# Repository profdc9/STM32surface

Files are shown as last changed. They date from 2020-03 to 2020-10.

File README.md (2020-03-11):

# STM32surface
This is a Bluepill-compatible devboard for the STM32F103C8T6 microcontroller.
It uses 0805 surface mount parts and a few through hole parts that can be easily obtained as
generic components.  It is intended to be an alternative should the 
should the Bluepill not be available, especially given the number of fake parts that have appeared lately.
The layout is somewhat optimized to be RFI resistant given it is a two-layer board
This material is copyrighted by Daniel Marks (KW4TI) and licensed under
the Creative Commons License CC-BY-SA 4.0.  Software is copyrighted using the zlib
open-source license.

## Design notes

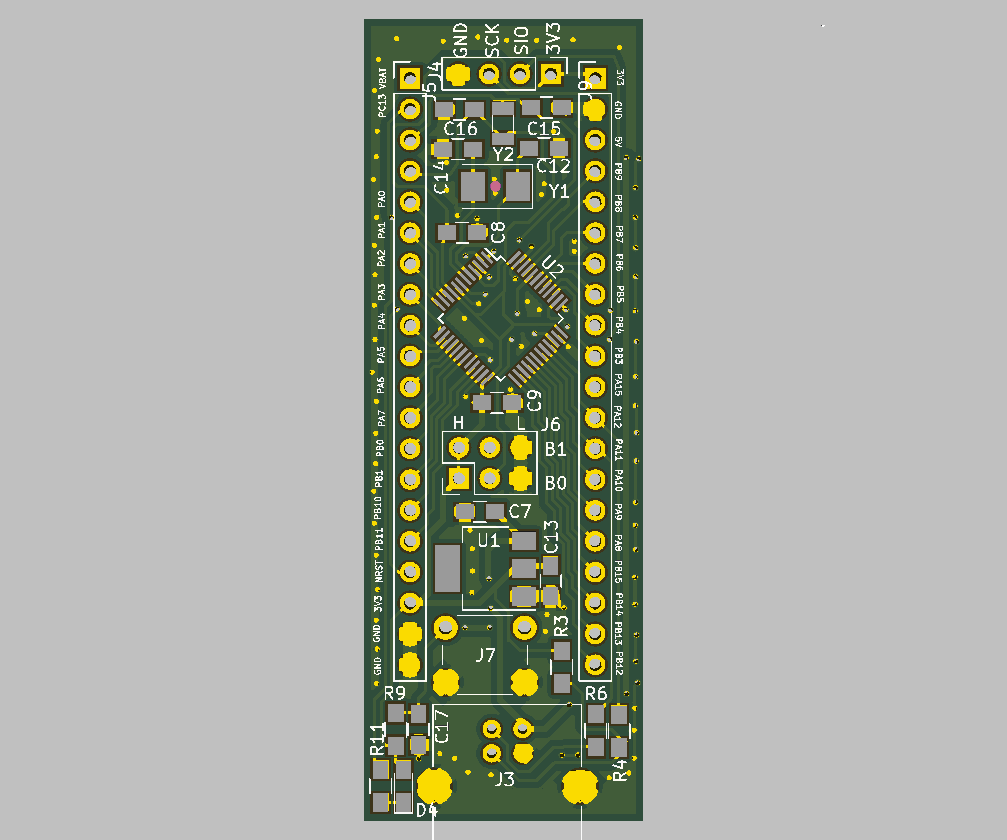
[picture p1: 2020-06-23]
STM32surface-bare.png

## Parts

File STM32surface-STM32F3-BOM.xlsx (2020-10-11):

Comment | Designator | Footprint | LCSC
20 pF | C12,C14,C15,C16 | Capacitors_SMD:C_0805_HandSoldering | C1804
1 uF | C13,C7 | Capacitors_SMD:C_0805_HandSoldering | C28323
10 nF | C17 | Capacitors_SMD:C_0805_HandSoldering | C1710
0.1 uF | C8,C9 | Capacitors_SMD:C_0805_HandSoldering | C49678
LED | D4 | LEDs:LED_0805_HandSoldering | C2296
USB_B | J3 | Connectors:USB_B
Conn_01x04 | J4 | Pin_Headers:Pin_Header_Straight_1x04_Pitch2.54mm
Conn_01x20 | J5,J9 | Pin_Headers:Pin_Header_Straight_1x20_Pitch2.54mm
Conn_02x03_Odd_Even | J6 | Pin_Headers:Pin_Header_Straight_2x03_Pitch2.54mm
Conn_01x02 | J7 | Buttons_Switches_THT:SW_PUSH_6mm
470R | R11 | Resistors_SMD:R_0805_HandSoldering | C17710
1.5k | R3,R9 | Resistors_SMD:R_0805_HandSoldering | C4310
22R | R4,R6 | Resistors_SMD:R_0805_HandSoldering | C17561
AMS1117-3V3 | U1 | TO_SOT_Packages_SMD:SOT-223 | C6186
STM32F103C8T6 | U2 | Housings_QFP:LQFP-48_7x7mm_Pitch0.5mm | C81523
8 MHz | Y1 | Crystals:Crystal_SMD_5032-2pin_5.0x3.2mm | C115962
Crystal | Y2 | Crystals:Crystal_SMD_3215-2pin_3.2x1.5mm | C32346

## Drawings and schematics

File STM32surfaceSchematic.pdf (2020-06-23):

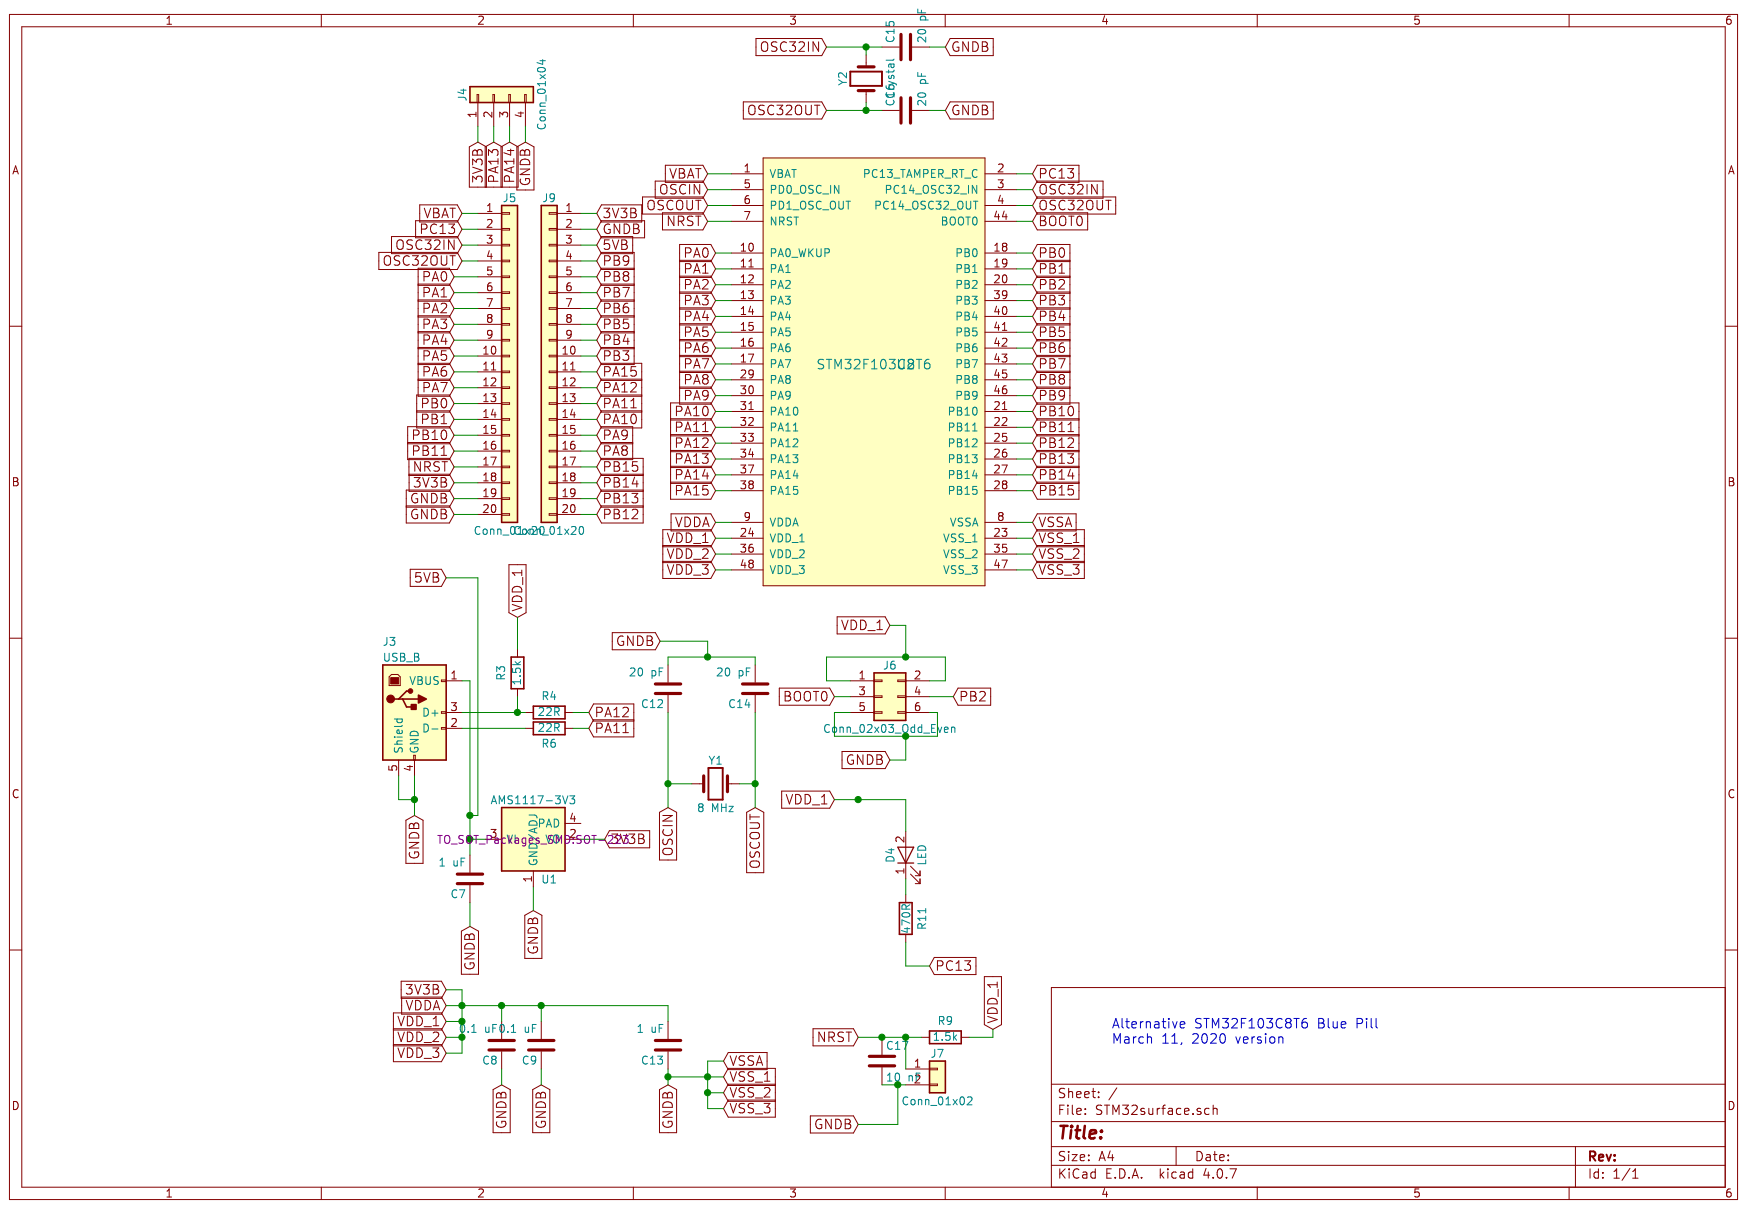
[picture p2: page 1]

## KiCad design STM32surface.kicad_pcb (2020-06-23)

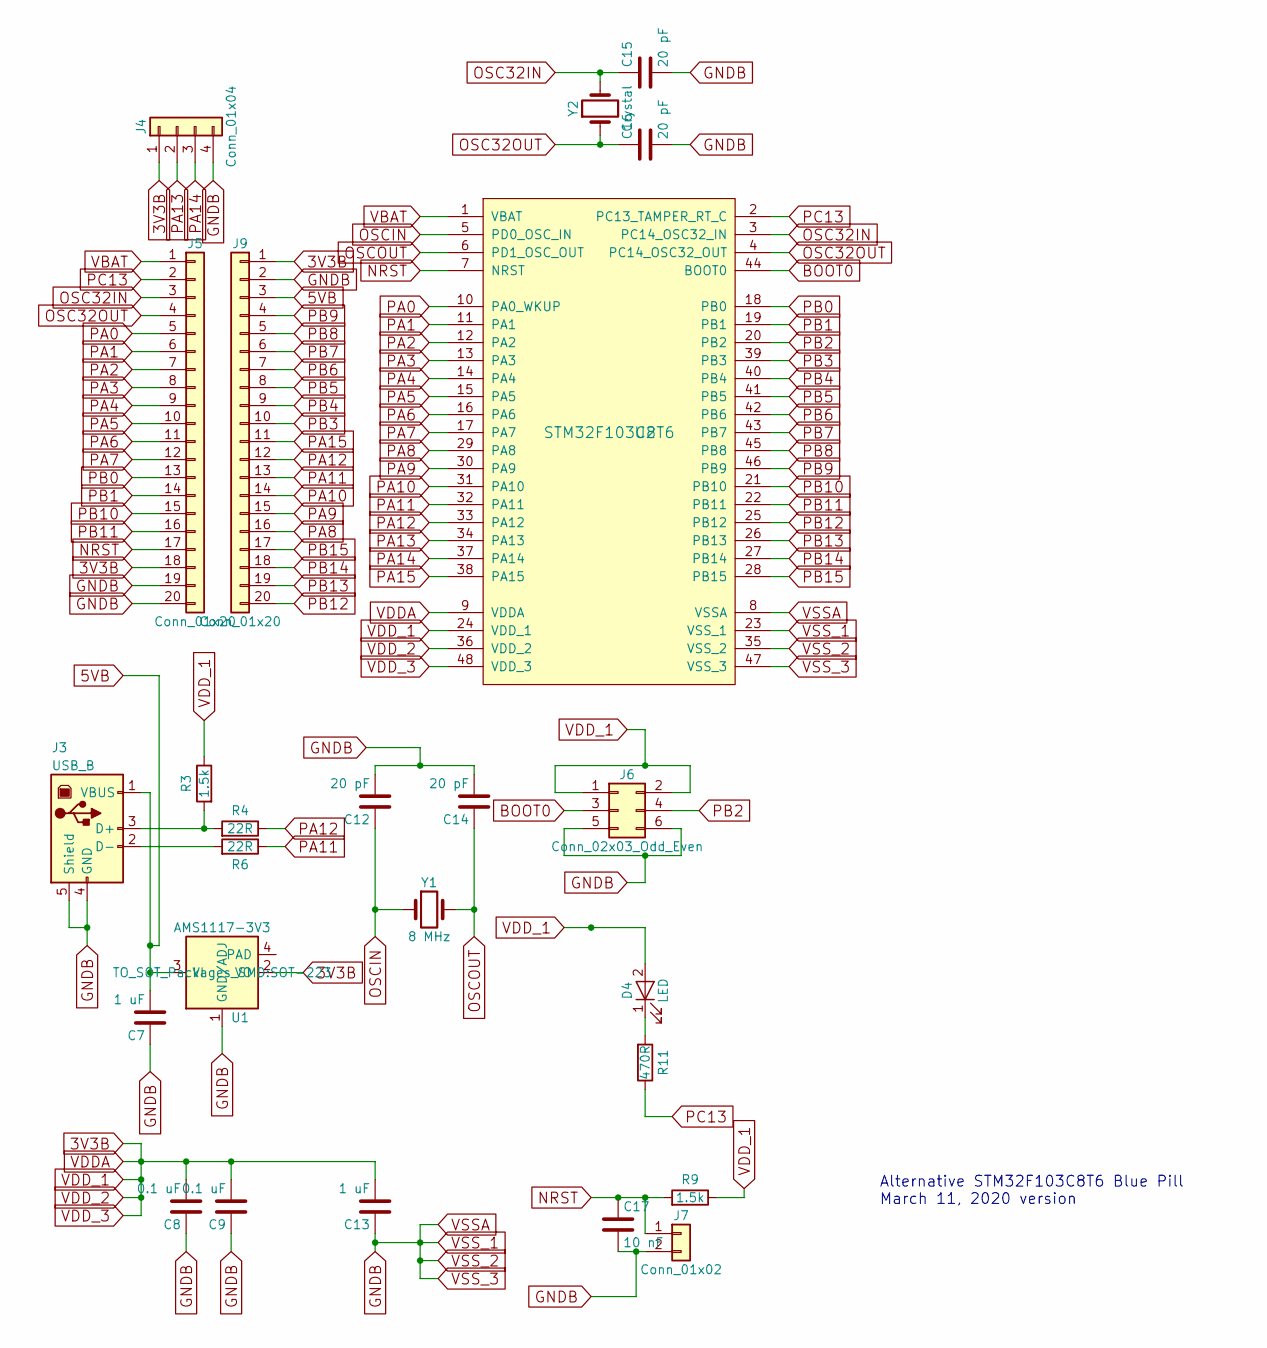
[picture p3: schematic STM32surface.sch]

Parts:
C7, C13: 1 uF; C_0805_HandSoldering; LCSC C28323
C8, C9: 0.1 uF; C_0805_HandSoldering; LCSC C49678
C12, C14, C15, C16: 20 pF; C_0805_HandSoldering; LCSC C1804
C17: 10 nF; C_0805_HandSoldering; LCSC C1710
D4: LED; LED_0805_HandSoldering; LCSC C2296
J3: USB_B
J4: Conn_01x04; Pin_Header_Straight_1x04_Pitch2.54mm
J5, J9: Conn_01x20; Pin_Header_Straight_1x20_Pitch2.54mm
J6: Conn_02x03_Odd_Even; Pin_Header_Straight_2x03_Pitch2.54mm
J7: Conn_01x02; SW_PUSH_6mm
R3, R9: 1.5k; R_0805_HandSoldering; LCSC C4310
R4, R6: 22R; R_0805_HandSoldering; LCSC C17561
R11: 470R; R_0805_HandSoldering; LCSC C17710
U1: AMS1117-3V3; SOT-223; MPN LM1117; LCSC C6186
U2: STM32F103C8T6; LQFP-48_7x7mm_Pitch0.5mm; LCSC C8304
Y1: 8 MHz; Crystal_SMD_5032-2pin_5.0x3.2mm; LCSC C115962
Y2: Crystal; Crystal_SMD_3215-2pin_3.2x1.5mm; LCSC C32346

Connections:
3V3B: C8.2, C9.2, C13.2, D4.2 (A), J4.1, J5.18, J6.1, J6.2, J9.1, R3.1, R9.1, U1.2 (VO), U2.9 (VDDA), U2.24 (VDD_1), U2.36 (VDD_2), U2.48 (VDD_3)
5VB: C7.2, J3.1 (VBUS), J9.3, U1.3 (VI)
BOOT0: J6.3, U2.44 (BOOT0)
GNDB: C7.1, C8.1, C9.1, C12.2, C13.1, C14.2, C15.2, C16.2, C17.2, J3.4 (GND), J3.5 (Shield), J4.4, J5.19, J5.20, J6.5, J6.6, J7.2, J9.2, U1.1 (GND/ADJ), U2.8 (VSSA), U2.23 (VSS_1), U2.35 (VSS_2), U2.47 (VSS_3)
NRST: C17.1, J5.17, J7.1, R9.2, U2.7 (NRST)
unnamed: D4.1 (K), R11.2
unnamed: J3.2 (D-), R6.2
unnamed: J3.3 (D+), R3.2, R4.2
OSC32IN: C15.1, J5.3, U2.3 (PC14_OSC32_IN), Y2.2
OSC32OUT: C16.1, J5.4, U2.4 (PC14_OSC32_OUT), Y2.1
OSCIN: C12.1, U2.5 (PD0_OSC_IN), Y1.1
OSCOUT: C14.1, U2.6 (PD1_OSC_OUT), Y1.2
PA0: J5.5, U2.10 (PA0_WKUP)
PA1: J5.6, U2.11 (PA1)
PA2: J5.7, U2.12 (PA2)
PA3: J5.8, U2.13 (PA3)
PA4: J5.9, U2.14 (PA4)
PA5: J5.10, U2.15 (PA5)
PA6: J5.11, U2.16 (PA6)
PA7: J5.12, U2.17 (PA7)
PA8: J9.16, U2.29 (PA8)
PA9: J9.15, U2.30 (PA9)
PA10: J9.14, U2.31 (PA10)
PA11: J9.13, R6.1, U2.32 (PA11)
PA12: J9.12, R4.1, U2.33 (PA12)
PA13: J4.2, U2.34 (PA13)
PA14: J4.3, U2.37 (PA14)
PA15: J9.11, U2.38 (PA15)
PB0: J5.13, U2.18 (PB0)
PB1: J5.14, U2.19 (PB1)
PB2: J6.4, U2.20 (PB2)
PB3: J9.10, U2.39 (PB3)
PB4: J9.9, U2.40 (PB4)
PB5: J9.8, U2.41 (PB5)
PB6: J9.7, U2.42 (PB6)
PB7: J9.6, U2.43 (PB7)
PB8: J9.5, U2.45 (PB8)
PB9: J9.4, U2.46 (PB9)
PB10: J5.15, U2.21 (PB10)
PB11: J5.16, U2.22 (PB11)
PB12: J9.20, U2.25 (PB12)
PB13: J9.19, U2.26 (PB13)
PB14: J9.18, U2.27 (PB14)
PB15: J9.17, U2.28 (PB15)
PC13: J5.2, R11.1, U2.2 (PC13_TAMPER_RT_C)
VBAT: J5.1, U2.1 (VBAT)

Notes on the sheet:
Alternative STM32F103C8T6 Blue Pill March 11, 2020 version

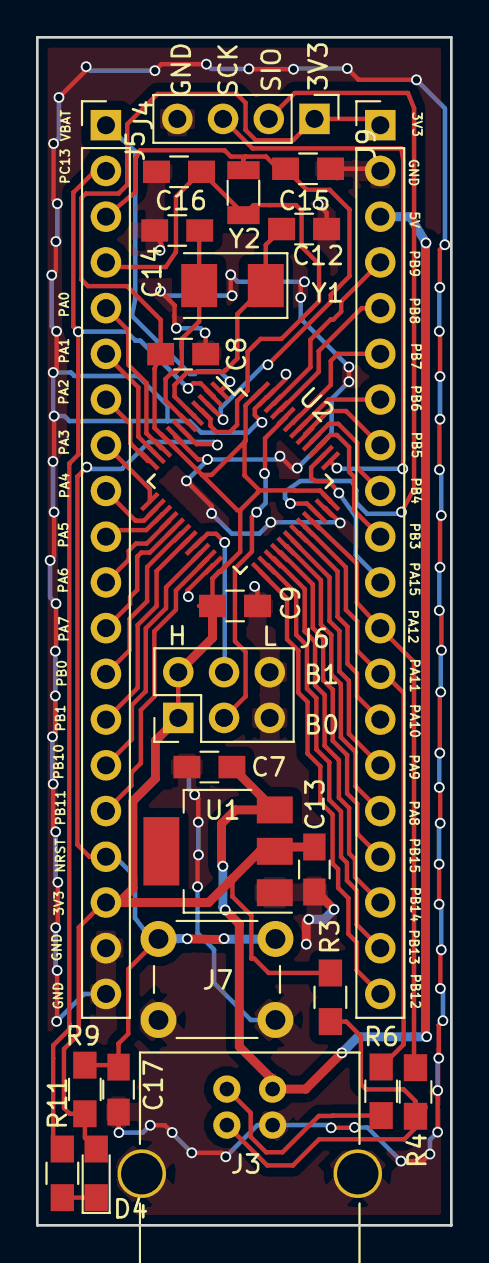
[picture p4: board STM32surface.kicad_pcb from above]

Board: 2 copper layers, 23.0 x 66.0 mm, 25 parts (0 on the bottom side), 46 nets.

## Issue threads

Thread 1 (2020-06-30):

Missing BOM/CPL file?

robcazzaro, 2020-06-30:
First of all, thanks for sharing this. I have a few "old and good" Blue Pills. and do no want to get a non-STM version

Since you explicitly mention that you selected only JLCPCB parts, I was hoping to also find an already created BOM/CPL file to get an immediate quote on their website. I know I could build my own, but before starting I wondered if maybe you meant to also add the BOM/CPL file and simply forgot, or if you do not plan to provide one

profdc9, 2020-06-30:
Ok, I added STM32surface-BOM.xlsx and STM32surface-top.xlsx to the project
and tested it on JLCPCB's web site.  It appears to look fine on the
rendering with correct placement of the components.  The price for 5 total
was $27.76 with the $2 for the PCBs.

Things that are not included are the 6 mm through-hole button for the reset
button and a USB-B connector.  The USB-B connector is the big type which I
prefer because it is very rugged and is very standardized and therefore is
easy to get.

Dan

profdc9, 2020-06-30:
Oh yeah, I forgot to mention the files are on the github...

Dan

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

robcazzaro, 2020-06-30:
Thanks!

Closed 2020-06-30.

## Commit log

2020-06-23 Changed all to JLCPCB parts
    [STM32surface-B.Cu.gbr, STM32surface-B.Mask.gbr, STM32surface-B.SilkS.gbr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]
2020-06-30 Added STM32surface-top.xlsx and STM32surface-BOM.xlsx
    [STM32surface-BOM.xlsx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]
2020-10-11 Added STM32F3 BOM
    [STM32surface-STM32F3-BOM.xlsx]
